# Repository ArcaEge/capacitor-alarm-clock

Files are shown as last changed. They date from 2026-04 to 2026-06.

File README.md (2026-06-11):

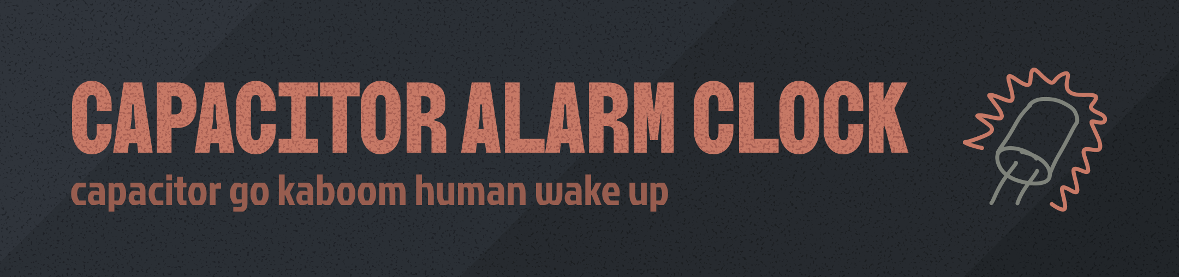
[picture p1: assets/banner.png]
capacitor alarm clock


<div align="center">
    <h1>
        capacitor alarm clock
    </h1>
    <p>
        <strong>
            wake up to the bang of a capacitor going off
        </strong>
    </p>
    <p>
        <a href="#features">Features</a> •
        <a href="#demo">Demo</a> •
        <a href="#pcb">PCB</a> •
        <a href="#cad-files">CAD</a> •
        <a href="#building--flashing-firmware">Firmware</a> •
        <a href="#usage">Usage</a>
    </p>
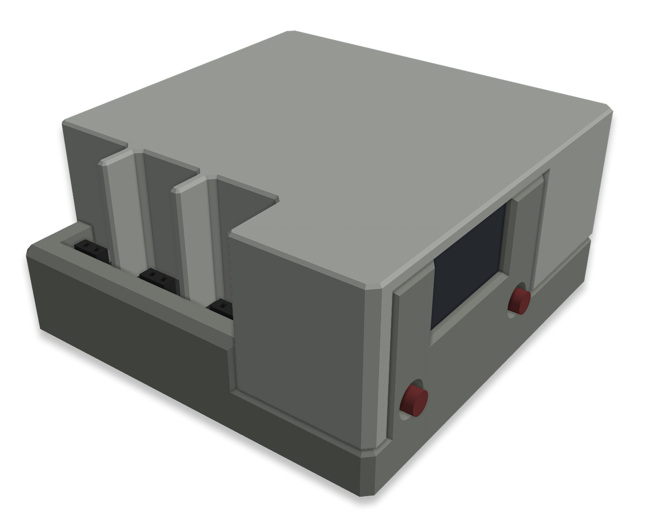
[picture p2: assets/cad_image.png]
CAD image
    
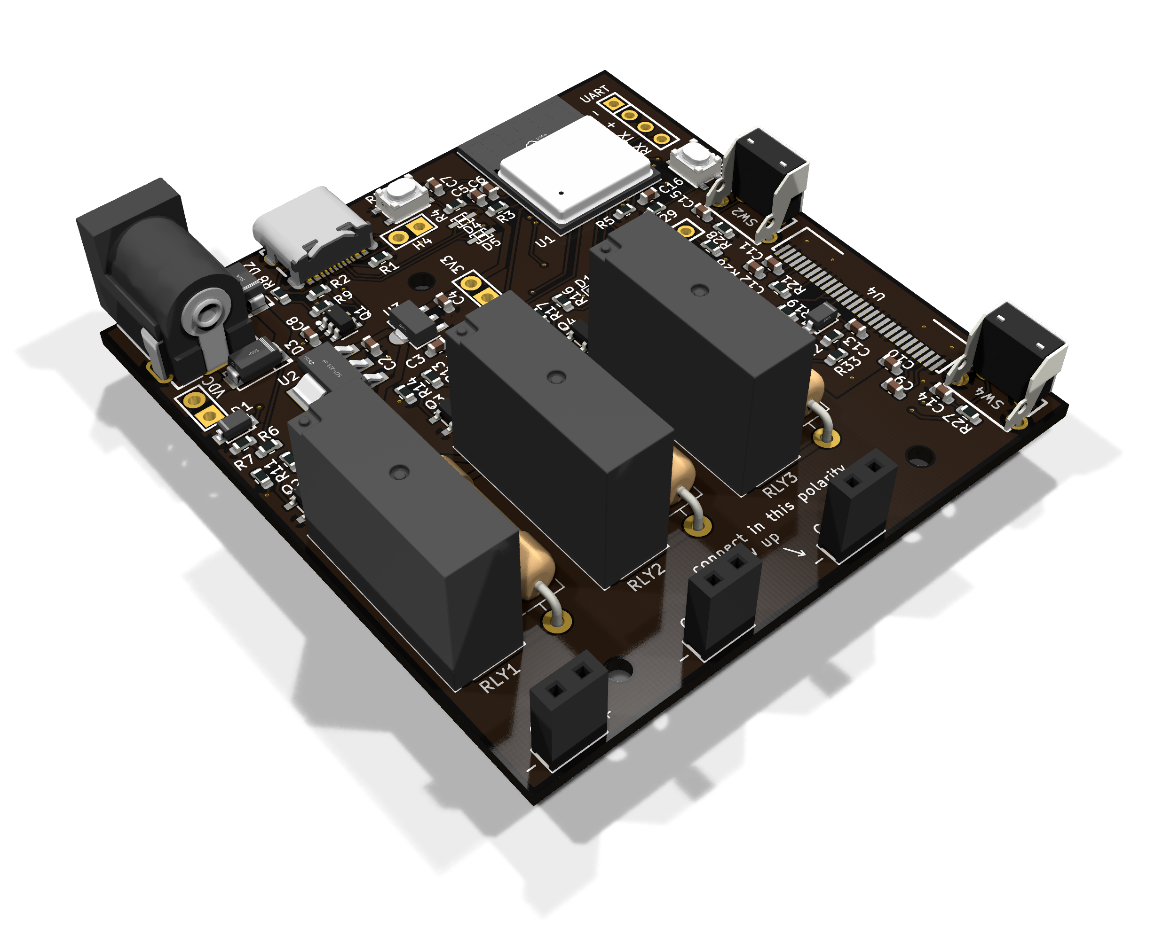
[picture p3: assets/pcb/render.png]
PCB render
    
</div>

## Why?

Why not?

This was originally inspired by ElectroBOOM's [capacitor alarm video](https://www.youtube.com/watch?v=5dYt34JIDGw); this is like a safer (?), more practical and more useable-ish version of that.

> [!WARNING]
> Take care when using this, and only do so if you know what you're doing. Capacitor explosions are quite violent and the fumes aren't nice to breathe. This project is mostly a high-effort joke and not something practical to use

## Features

- ESP32-powered
  - Configure settings via the webserver
  - Fetch time automatically via NTP
- 128x64 SSD1315 display
- 3 separate capacitor slots
- Up to 3A through the capacitors
  - 10 ohm current limiting resistors to avoid brownouts if the capacitor shorts
- Power via USB-C or barrel jack (12-15V)
- Small size (72x74x36mm)

Here's how it looks:

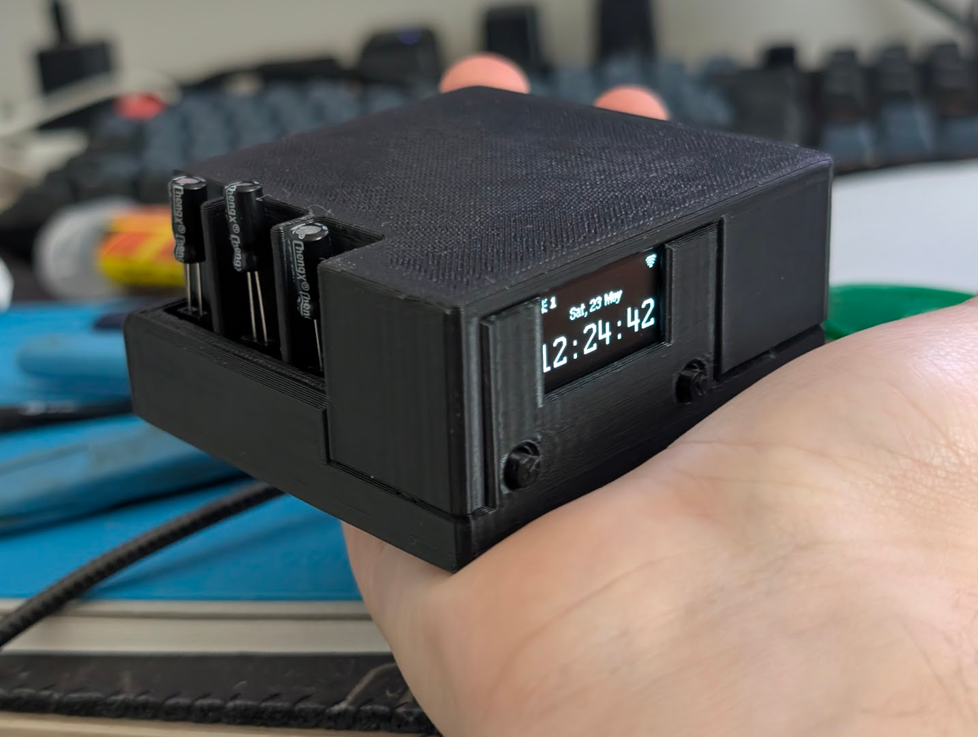
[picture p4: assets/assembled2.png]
assembled capacitor alarm clock resting on hand


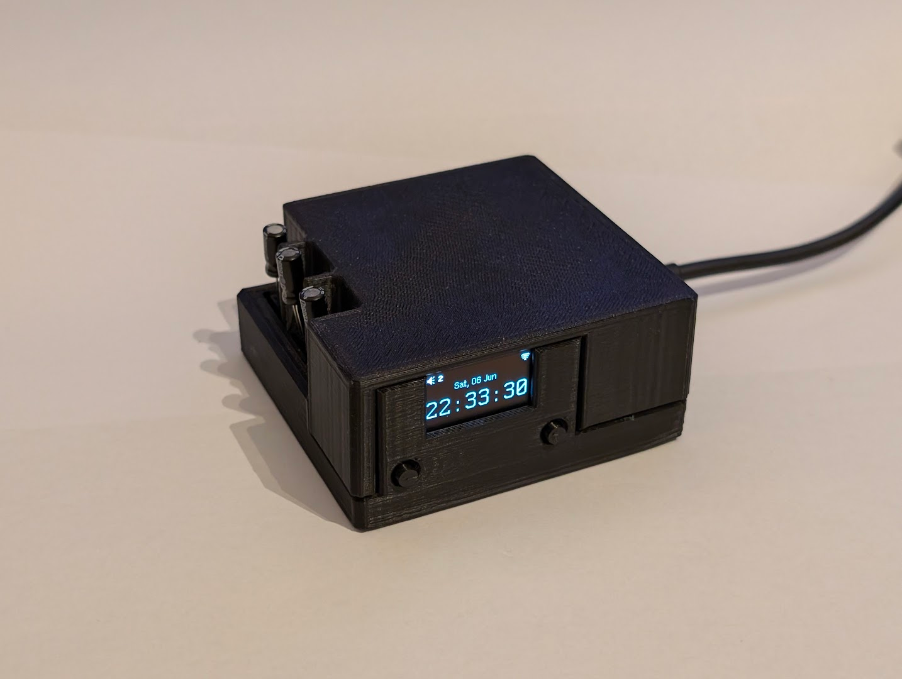
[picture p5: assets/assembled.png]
assembled


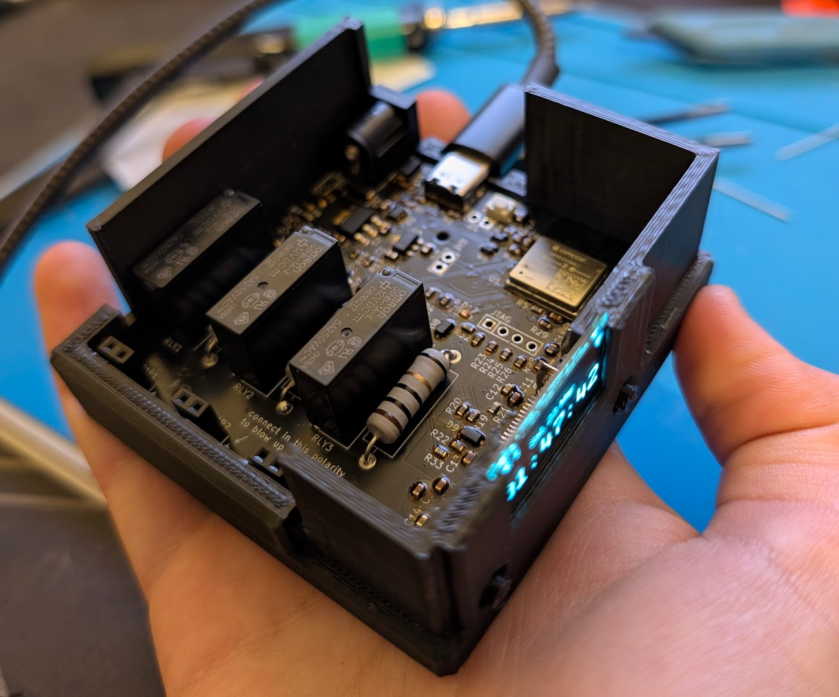
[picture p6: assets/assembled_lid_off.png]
assembled


## Demo

Also on YouTube [here](https://youtu.be/eKc19qRxZ5o)

https://github.com/user-attachments/assets/c24133be-e630-4c25-ad7a-87afec26e37d

## PCB

Images of schematics and more are under the [PCB README](pcb/README.md). A BOM is available under [production](production/). I'd recommend using [JLCPCB](https://jlcpcb.com/) as they seem to have the lowest prices.

<a href="pcb/README.md">
    
</a>

## CAD files

CAD files for the shell and PCB are under [`cad/`](cad/). The README there contains more info, but the Onshape project is available [here](https://cad.onshape.com/documents/62d468c7ff14a2e83cb50980/w/ededd05b0c271bca944a2c41/e/b2699bc116bdf7662263df84).

## Building + flashing firmware

To build and flash the firmware, you'll need to use PlatformIO. Install the VSCode extension and open the firmware folder, then follow the instructions in the [firmware README](firmware/README.md).

## Usage

Once flashed and connected to WiFi, the display will show the current time. You can go into the settings by pressing "select" (done by pressing both buttons at once). From there, you can use the left and right buttons to go up and down and set the alarm time, schedule, next capacitor slot and more. You can also go into the "about" page to see the clock's IP.

Once you have the IP, you can go to the web interface at `http://<IP>/`. Note: some browsers might only try HTTPS (looking at you Firefox), so you'll need to manually enter the `http://` part.

> [!NOTE]
> The voltage regulators might heat up a bit during use, this is normal as there's ~12V of voltage drop across them. It might be a better idea to use a buck converter circuit instead of voltage regulators to step down the voltage. I chose voltage regulators to save on board space, but they do get quite hot. A buck converter circuit would also enable the use of higher input voltages, as the limiting factor right now is thermals.

## Sourcing capacitors

When choosing capacitors, you should avoid capacitors with these pressure release slots at the top, as they will reduce the bang. Choose the biggest capacitor you can get that has no top slot.

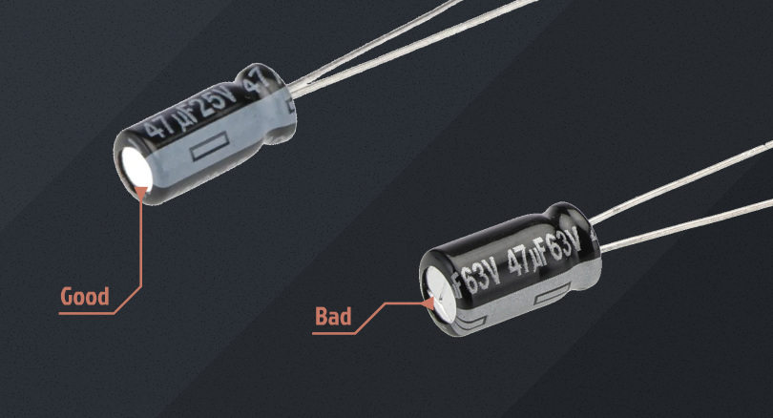
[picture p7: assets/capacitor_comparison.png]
capacitor comparison


Also try to go as low as possible with the voltage rating to increase reliability, ~16V is where you should aim. [These capacitors](https://www.lcsc.com/product-detail/C22320.html) from LCSC are pretty good, at $3 for 200.

## Magazine page

This project was submitted to [Hack Club Fallout](https://fallout.hackclub.com)! Here's the page for the Fallout magazine:

<a href="assets/magazine/magazine.pdf">
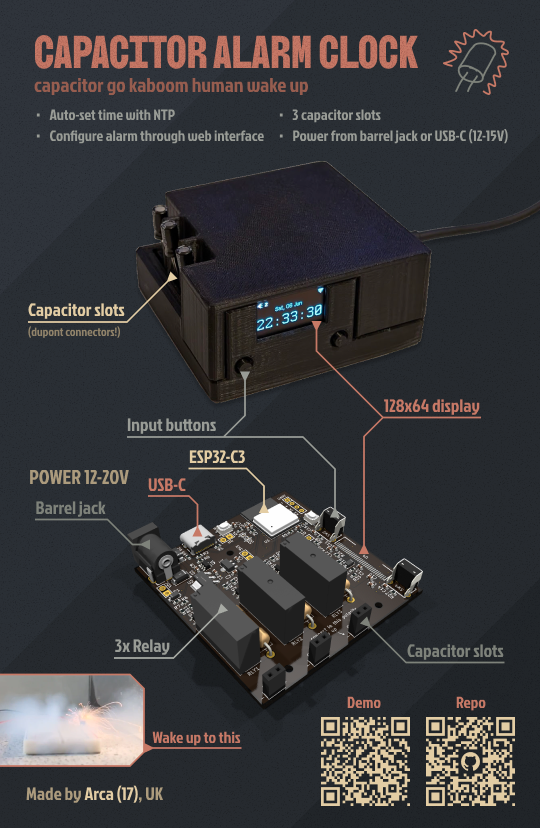
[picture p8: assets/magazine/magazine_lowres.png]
magazine page
    
</a>

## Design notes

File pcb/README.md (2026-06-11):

# PCB files

If you're looking for the production files, they're under [`../production/`](../production/)

PCB render

## PCB

### Front

front

### Back

back

## Schematics

I used hierarchical schematics whilst designing this, this is split into multiple files

### `capacitor-alarm-clock.kicad_sch`

capacitor-alarm-clock.kicad_sch

### `esp32.kicad_sch`

esp32.kicad_sch

### `power.kicad_sch`

power.kicad_sch

### `usb.kicad_sch`

usb.kicad_sch

### `relays.kicad_sch`

relays.kicad_sch

### `display.kicad_sch`

display.kicad_sch

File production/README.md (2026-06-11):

# Production files

## BOM

- [`bom_pcb_components.csv`](bom_pcb_components.csv) - BOM for the PCB components
- [`bom_general.csv`](bom_general.csv) - general BOM with prices

All the electrical components are from LCSC, as it's cheaper.

### LCSC cart

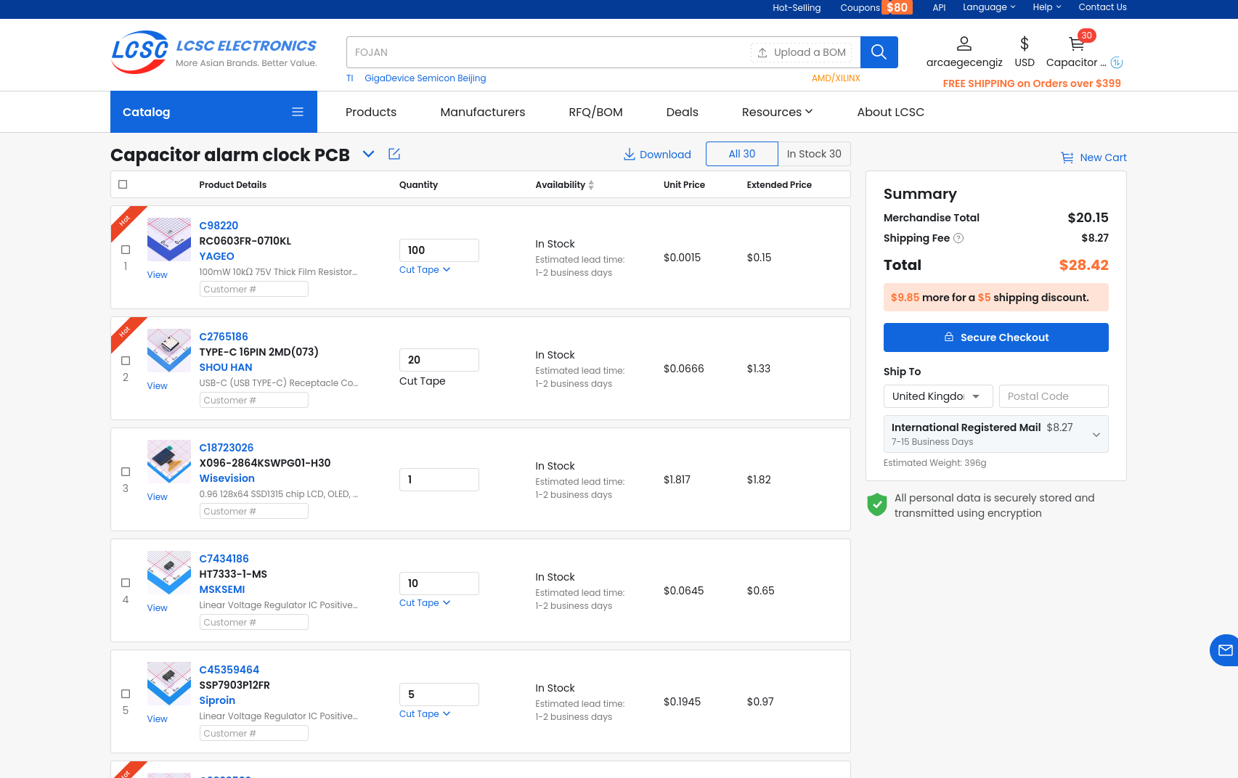
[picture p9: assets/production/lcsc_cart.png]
LCSC cart


## Gerbers & drill files

Under `gerber_drl` and also as a zip at `gerber_drl.zip`

### JLCPCB cart

JLCPCB seems to be the best place to order this, at $2 before shipping:

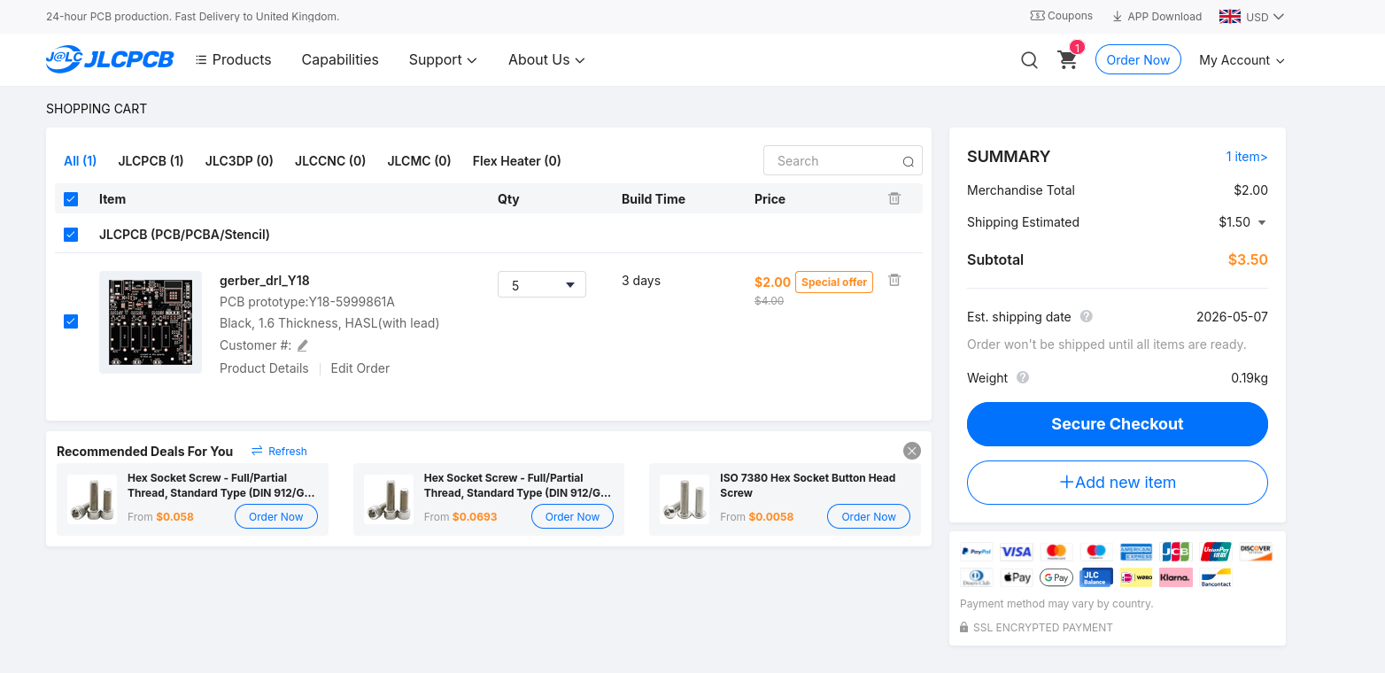
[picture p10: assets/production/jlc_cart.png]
JLCPCB cart


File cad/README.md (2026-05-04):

# CAD files

The Onshape project is [available here](https://cad.onshape.com/documents/62d468c7ff14a2e83cb50980/w/ededd05b0c271bca944a2c41/e/b2699bc116bdf7662263df84)

The top and bottom halves are held together via a friction fit to reduce the need for screws. However, you'll still need M2x5 screws for mounting the PCB to the bottom enclosure.

Takes around 60g of filament to print.

CAD

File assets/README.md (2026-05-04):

# Assets

3D PCB renders were generated with KiCAD CLI, using the `render` command.

Banner and poster designs were designed in Figma, [available here](https://www.figma.com/design/jmvWcAlcJrcGd9PXcn2myq/Capacitor-alarm-clock). The colour palette used is from [here](https://colordesigner.io/color-palette-builder#703030-2F343B-7E827A-E3CDA4-C77966).

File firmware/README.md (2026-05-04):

# firmware

Before compilation, copy `src/config.h.example` to `config.h` and add your WiFi credentials, along with your timezone string. You can then upload to the board.

I didn't have an ESP32 whilst working on the firmware as the parts hadn't arrived yet, so you can also compile this to run on an ESP8266. Choose `nodemcuv2` as the build target to do this. The pinout is in `inputs.hpp`, `alarm.cpp` and `display.hpp`.

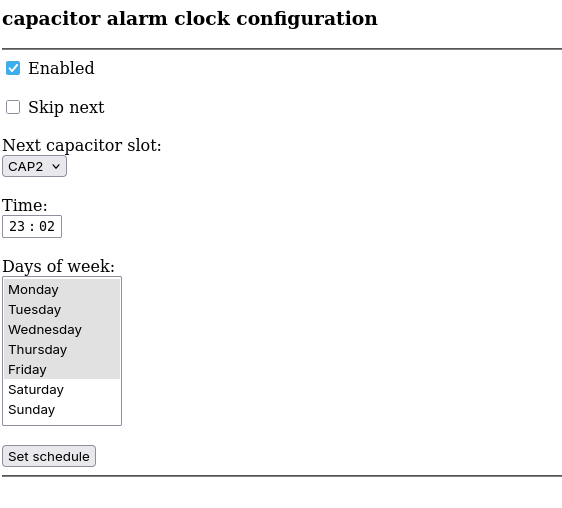
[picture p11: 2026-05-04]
assets/web_config.png

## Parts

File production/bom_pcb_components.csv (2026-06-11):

Reference | Value | Qty | Footprint | Manufacturer Part | Supplier | Supplier Part | Supplier Part URL
C1,C2,C3,C4,C5,C13 | 10u | 6 | Capacitor_SMD:C_0603_1608Metric | CL10A106MA8NRNC | LCSC | C96446 | https://www.lcsc.com/product-detail/C96446.html
C6 | 0.1u | 1 | Capacitor_SMD:C_0603_1608Metric | CC0603KRX7R9BB104 | LCSC | C14663 | https://www.lcsc.com/product-detail/C14663.html
C7,C8,C9,C10,C14,C15,C16 | 1u | 7 | Capacitor_SMD:C_0603_1608Metric | CL10B105KA8NNNC | LCSC | C29936 | https://www.lcsc.com/product-detail/C29936.html
C11 | 4.7u | 1 | Capacitor_SMD:C_0603_1608Metric | CL10A475KO8NNNC | LCSC | C19666 | https://www.lcsc.com/product-detail/C19666.html
C12 | 2.2u | 1 | Capacitor_SMD:C_0603_1608Metric | CL10A225KO8NNNC | LCSC | C23630 | https://www.lcsc.com/product-detail/C23630.html
D1 | 3V3 | 1 | EasyEDA_Lib:SOD-123_L2.7-W1.6-LS3.7-RD | BZT52C3V3 | LCSC | C173413 | https://www.lcsc.com/product-detail/C173413.html
D2,D3 |  | 2 | EasyEDA_Lib:SMA_L4.4-W2.6-LS5.0-RD | B340A-13-F | LCSC | C85098 | https://www.lcsc.com/product-detail/C85098.html
D4,D5 |  | 2 | EasyEDA_Lib:SOD-323_L1.8-W1.3-LS2.5-BI | PESD5V0U1BA-N | LCSC | C406223 | https://www.lcsc.com/product-detail/C406223.html
D6,D7,D8,D9 |  | 4 | EasyEDA_Lib:SOD-123_L2.7-W1.6-LS3.7-RD | 1N5819HW-7-F | LCSC | C82544 | https://www.lcsc.com/product-detail/C82544.html
D10,D11,D12 | LED | 3 | LED_SMD:LED_0603_1608Metric | YLED0603R | LCSC | C19171390 | https://www.lcsc.com/product-detail/C19171390.html
DC1 |  | 1 | EasyEDA_Lib:DC-IN-TH_DC-005-A200 | DC-005-A200 | LCSC | C720557 | https://www.lcsc.com/product-detail/C720557.html
H6,H7,H8 |  | 3 | EasyEDA_Lib:HDR-TH_2P-P2.54-V-F | ZX-PM2.54-1-2PY | LCSC | C7499322 | https://www.lcsc.com/product-detail/C7499322.html
Q1 |  | 1 | EasyEDA_Lib:SOT-23-6_L2.9-W1.6-P0.95-LS2.8-BL-2 | CH221K | LCSC | C5125736 | https://www.lcsc.com/product-detail/C5125736.html
Q2,Q3,Q4 |  | 3 | EasyEDA_Lib:SOT-23-3_L2.9-W1.6-P1.90-LS2.8-BR | BC817-40,215 | LCSC | C52801 | https://www.lcsc.com/product-detail/C52801.html
R1,R2,R19,R20,R22 | 5K1 | 5 | Resistor_SMD:R_0603_1608Metric | FRC0603F5101TS | LCSC | C2907044 | https://www.lcsc.com/product-detail/C2907044.html
R3,R4,R5,R6,R11,R14,R17,R27,R28,R29 | 10K | 10 | Resistor_SMD:R_0603_1608Metric | RC0603FR-0710KL | LCSC | C98220 | https://www.lcsc.com/product-detail/C98220.html
R7 | 62K | 1 | Resistor_SMD:R_0603_1608Metric | RC0603FR-0762KL | LCSC | C137694 | https://www.lcsc.com/product-detail/C137694.html
R8,R10,R13,R16,R30,R31,R32,R33 | 1K | 8 | Resistor_SMD:R_0603_1608Metric | RC0603FR-071KL | LCSC | C22548 | https://www.lcsc.com/product-detail/C22548.html
R9 | 100K | 1 | Resistor_SMD:R_0603_1608Metric | FRC0603F1003TS | LCSC | C2906980 | https://www.lcsc.com/product-detail/C2906980.html
R12,R15,R18 | 10R | 3 | Resistor_THT:R_Axial_DIN0516_L15.5mm_D5.0mm_P20.32mm_Horizontal | MOF3WS-5.1Ω±5% T | LCSC | C121777 | https://www.lcsc.com/product-detail/C121777.html
R21 | 620K | 1 | Resistor_SMD:R_0603_1608Metric | 0603WAF6203T5E | LCSC | C23219 | https://www.lcsc.com/product-detail/C23219.html
R23,R24,R25,R26 | 0R | 4 | Resistor_SMD:R_0603_1608Metric | RC0603JR-070RL | LCSC | C95177 | https://www.lcsc.com/product-detail/C95177.html
RLY1,RLY2,RLY3 |  | 3 | EasyEDA_Lib:RELAY-TH_G5NB-1A-E-DCXX | G5NB-1A-E DC12 | LCSC | C225714 | https://www.lcsc.com/product-detail/C225714.html
SW1,SW3 |  | 2 | EasyEDA_Lib:SW-SMD_4P-L4.2-W3.3-P2.15-LS5.1 | TS-1089S-02526 | LCSC | C455282 | https://www.lcsc.com/product-detail/C455282.html
SW2,SW4 |  | 2 | EasyEDA_Lib:SW-TH_TS665ZJ | TS665ZJ | LCSC | C557599 | https://www.lcsc.com/product-detail/C557599.html
U1 |  | 1 | EasyEDA_Lib:WIFIM-SMD_ESP32-C3-MINI-1 | ESP32-C3-MINI-1-N4 | LCSC | C2838502 | https://www.lcsc.com/product-detail/C2838502.html
U2 |  | 1 | EasyEDA_Lib:SOT-223_L6.3-W3.5-P2.30-LS7.0-BR | SSP7903P12FR | LCSC | C45359464 | https://www.lcsc.com/product-detail/C45359464.html
U3 |  | 1 | EasyEDA_Lib:SOT-223-3_L6.5-W3.4-P2.30-LS7.0-BR-1 | SSP7903P33FR | LCSC | C5199839 | https://www.lcsc.com/product-detail/C5199839.html
U4 |  | 1 | EasyEDA_Lib:OLED-SMD_X096-2864KSWPG01-H30 | X096-2864KSWPG01-H30 | LCSC | C18723026 | https://www.lcsc.com/product-detail/C18723026.html
USB1 |  | 1 | EasyEDA_Lib:USB-C-SMD_TYPE-C-6PIN-2MD-073 | TYPE-C 16PIN 2MD(073) | LCSC | C2765186 | https://www.lcsc.com/product-detail/C2765186.html

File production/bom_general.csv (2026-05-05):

Thing | Qty needed | URL | Cost (without shipping, $)
PCB | 1 | https://jlcpcb.com/ | 2.00
Components | - | https://www.lcsc.com/ | 20.15
Capacitors | 100 | https://www.lcsc.com/product-detail/C22320.html | 1.50
M2x5 screws | 3 | https://jlcmc.com/product/s/E02/EDLA/din-912-gb-t-70.1-standard-socket-head-cap-screws-full---half-thread (part number EDLA-J9-M2-L5) | 0.04

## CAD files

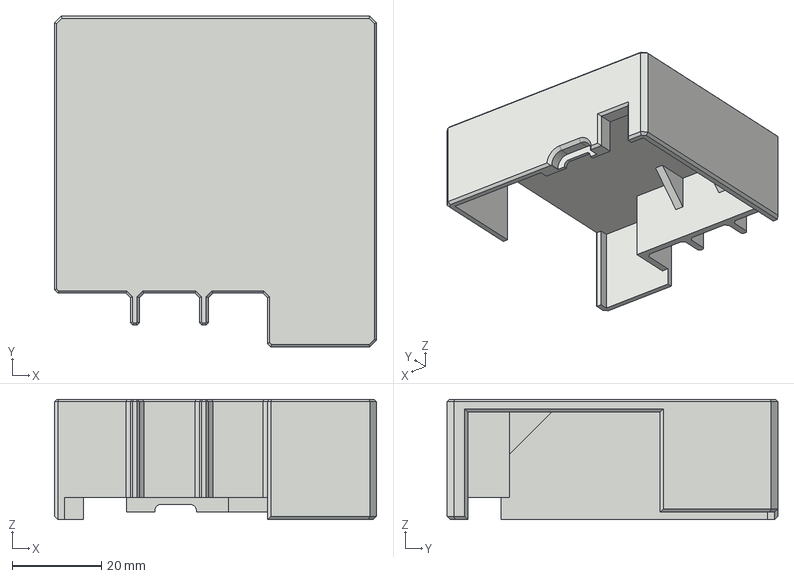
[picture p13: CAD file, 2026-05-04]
cad/step/top_enclosure.step
72.3 x 74.3 x 27.0 mm

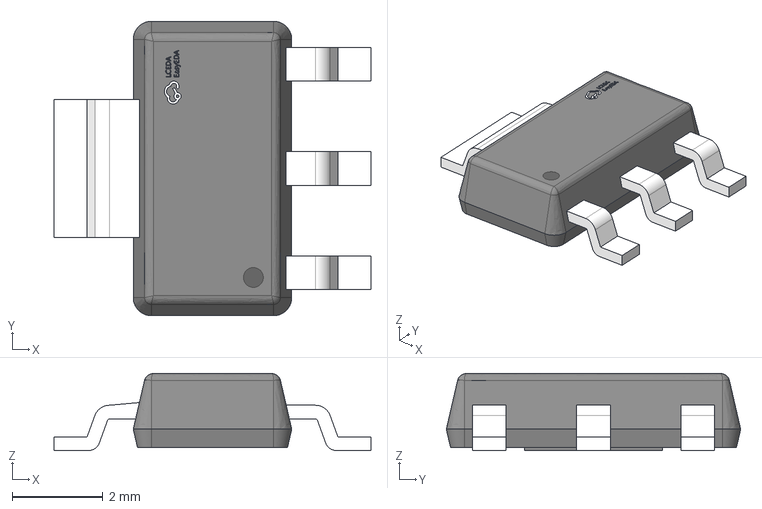
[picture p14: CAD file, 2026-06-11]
pcb/EASYEDA_MODELS/SOT-223-3_L6.5-W3.4-P2.30-LS7.0-BR-1.step
7.00 x 6.50 x 1.70 mm

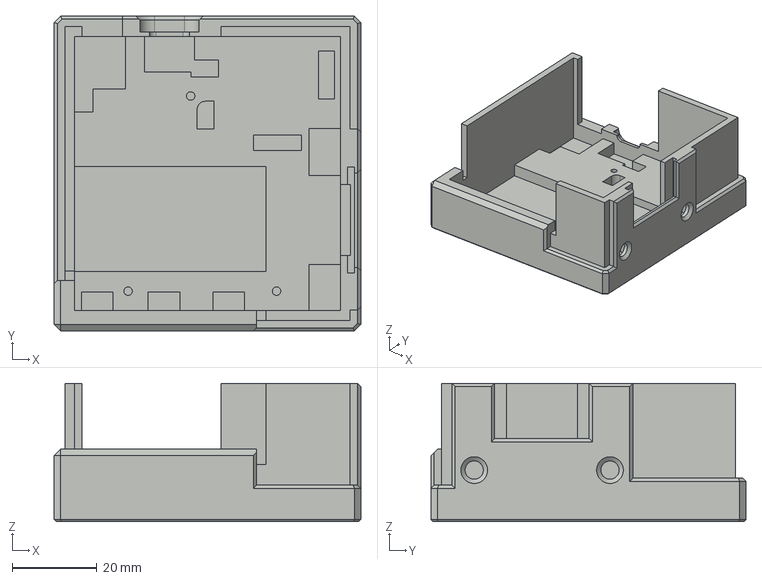
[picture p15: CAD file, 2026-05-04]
cad/step/bottom_enclosure.step
72.3 x 74.3 x 32.6 mm

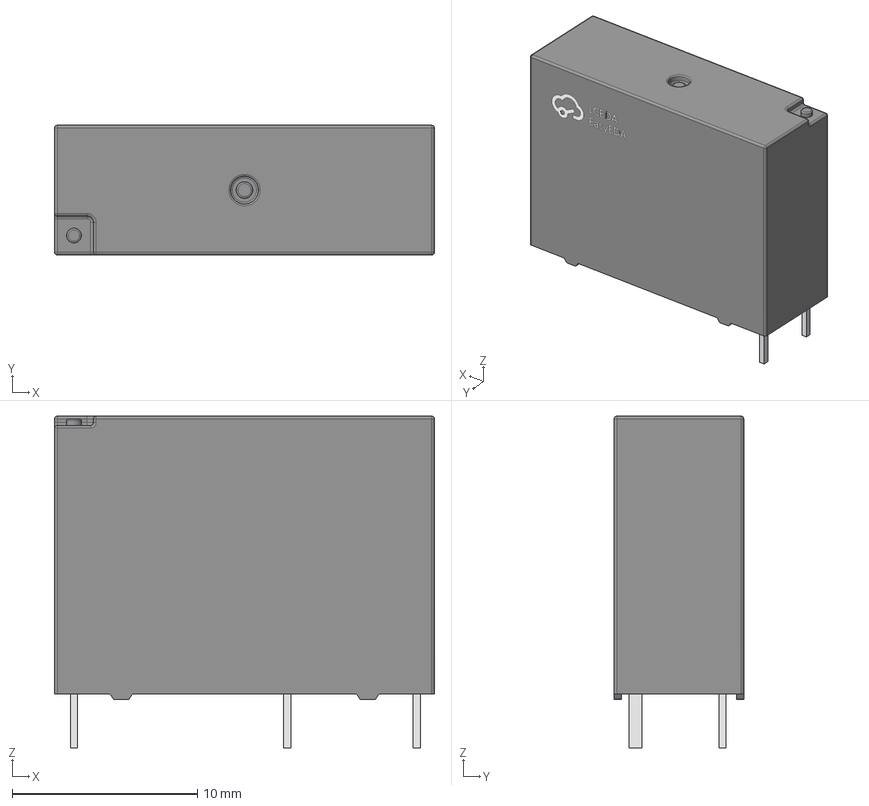
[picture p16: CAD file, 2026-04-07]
pcb/EASYEDA_MODELS/RELAY-TH_L20.5-W7.0-H15.0.step
20.5 x 7.01 x 17.9 mm

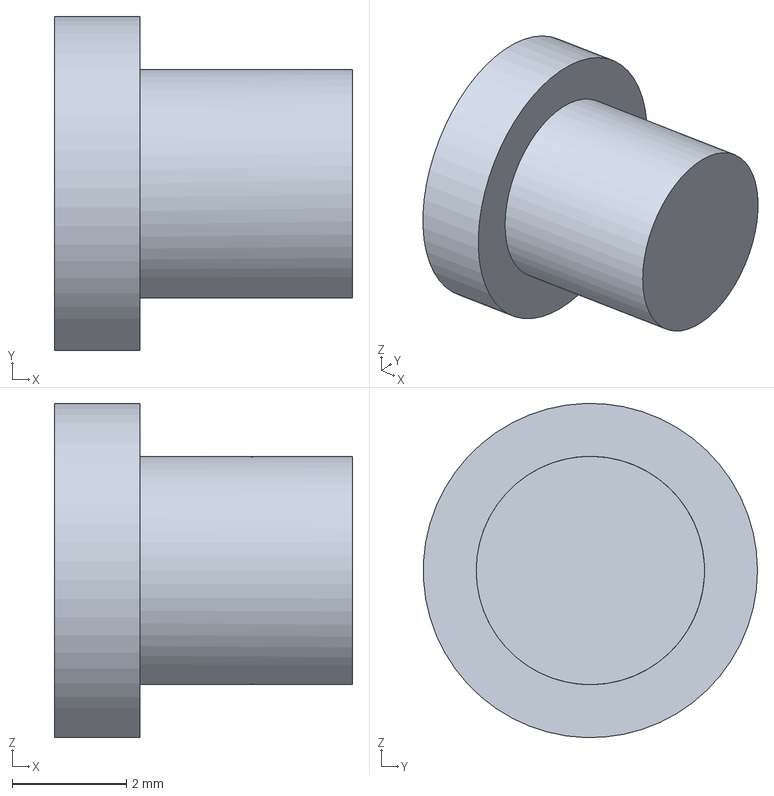
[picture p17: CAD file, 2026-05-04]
cad/step/button.step
5.23 x 5.85 x 5.85 mm

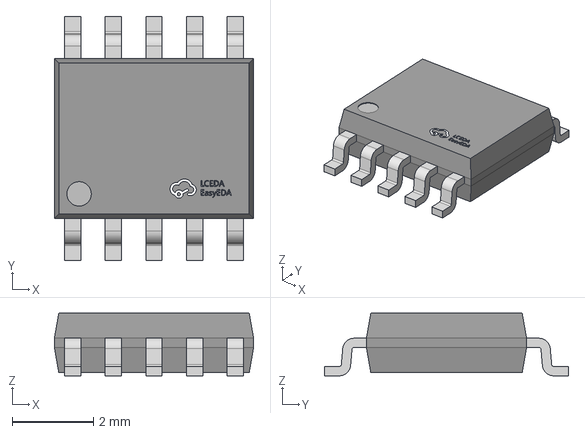
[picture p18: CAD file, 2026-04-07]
pcb/EASYEDA_MODELS/ESSOP-10_L4.9-W3.9-P1.0-LS6.0-TL-EP.step
4.90 x 6.00 x 1.54 mm

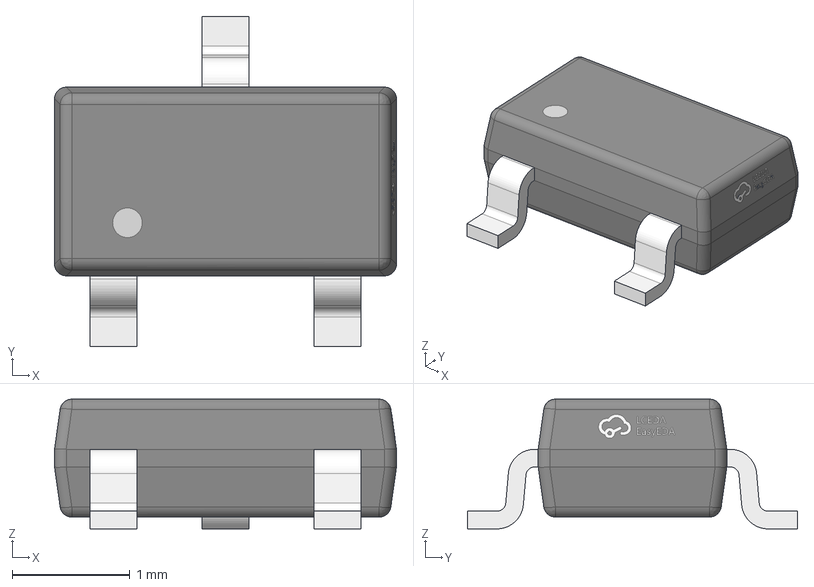
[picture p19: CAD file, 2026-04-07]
pcb/EASYEDA_MODELS/SOT-23-3L_L2.9-W1.6-H1.1-LS2.8-P0.95.step
2.90 x 2.80 x 1.10 mm

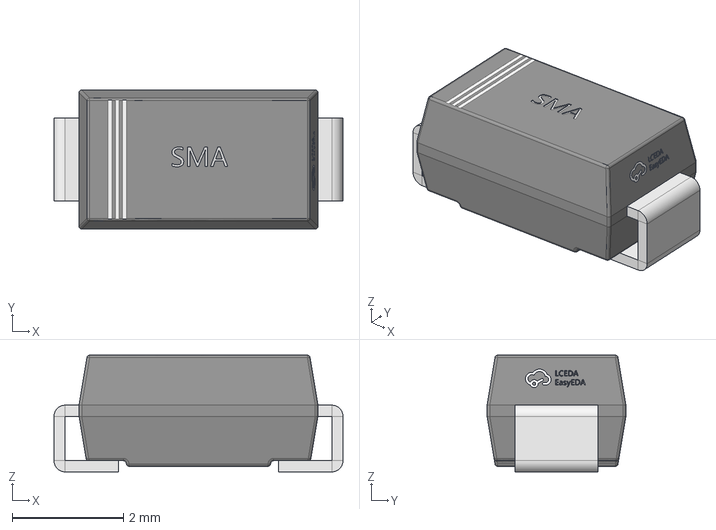
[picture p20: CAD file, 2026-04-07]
pcb/EASYEDA_MODELS/SMA_L4.4-W2.6-LS5.0-RD.step
5.20 x 2.50 x 2.10 mm

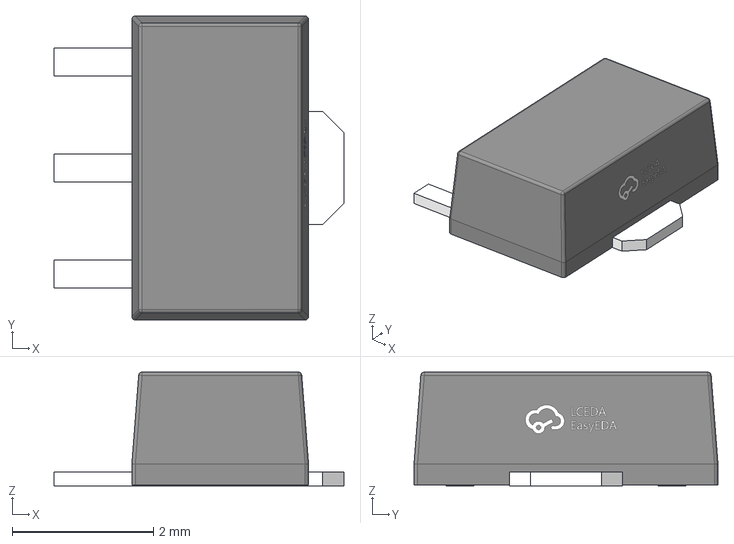
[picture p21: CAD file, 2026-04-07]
pcb/EASYEDA_MODELS/SOT-89-3_L4.3-W2.5-H1.6-LS4.1-P1.50.step
4.10 x 4.30 x 1.61 mm

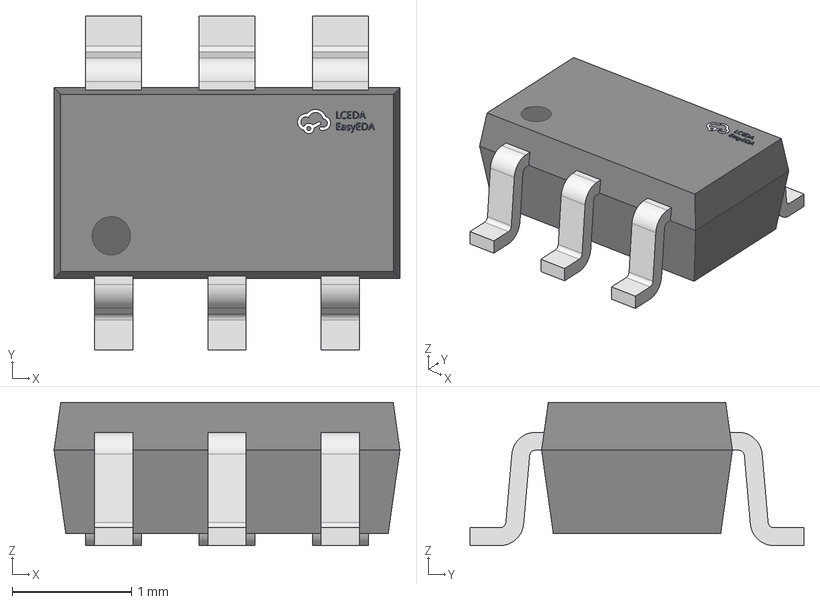
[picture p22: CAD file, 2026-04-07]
pcb/EASYEDA_MODELS/SOT-23-6_L2.9-W1.6-P0.95-LS2.8-BL-2.step
2.90 x 2.80 x 1.20 mm

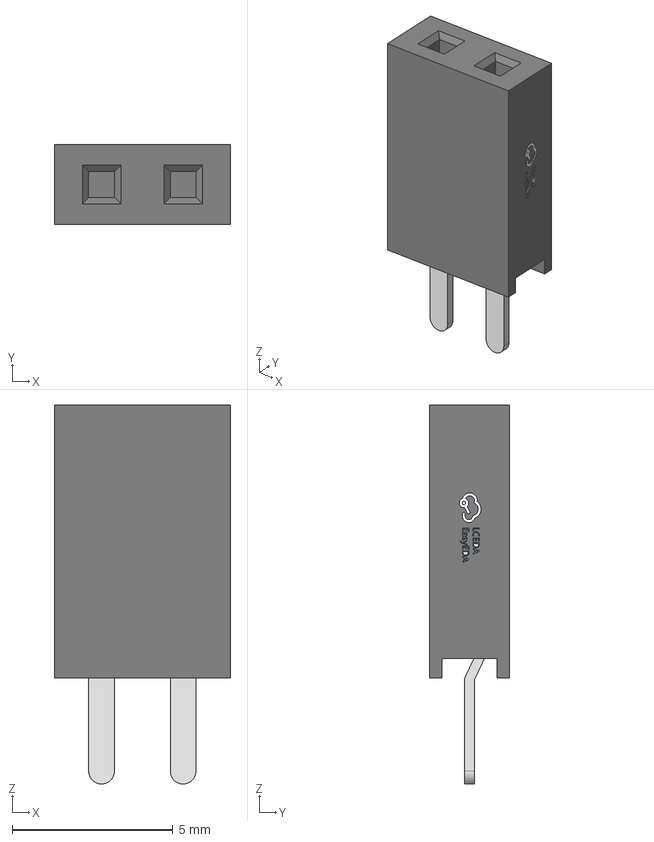
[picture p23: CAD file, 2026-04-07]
pcb/EASYEDA_MODELS/HDR-TH_2P-P2.54-F-LI-1X2P.step
5.49 x 2.50 x 11.8 mm

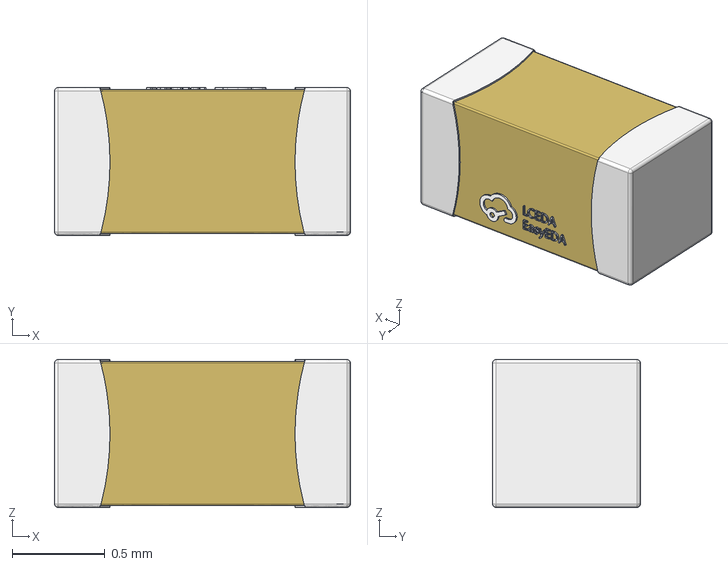
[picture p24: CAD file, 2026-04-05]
pcb/EASYEDA_MODELS/C0603_L1.6-W0.8-H0.8.step
1.60 x 0.8 x 0.8 mm

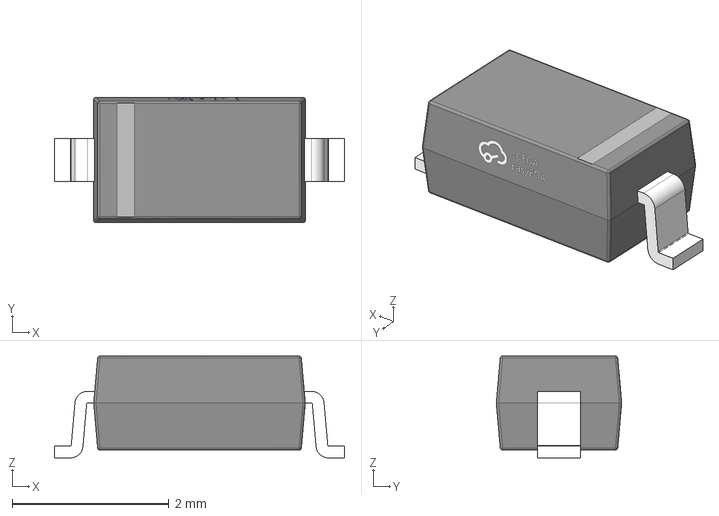
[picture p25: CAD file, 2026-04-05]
pcb/EASYEDA_MODELS/SOD-123_L2.7-W1.6-H1.4-LS3.7.step
3.70 x 1.60 x 1.30 mm

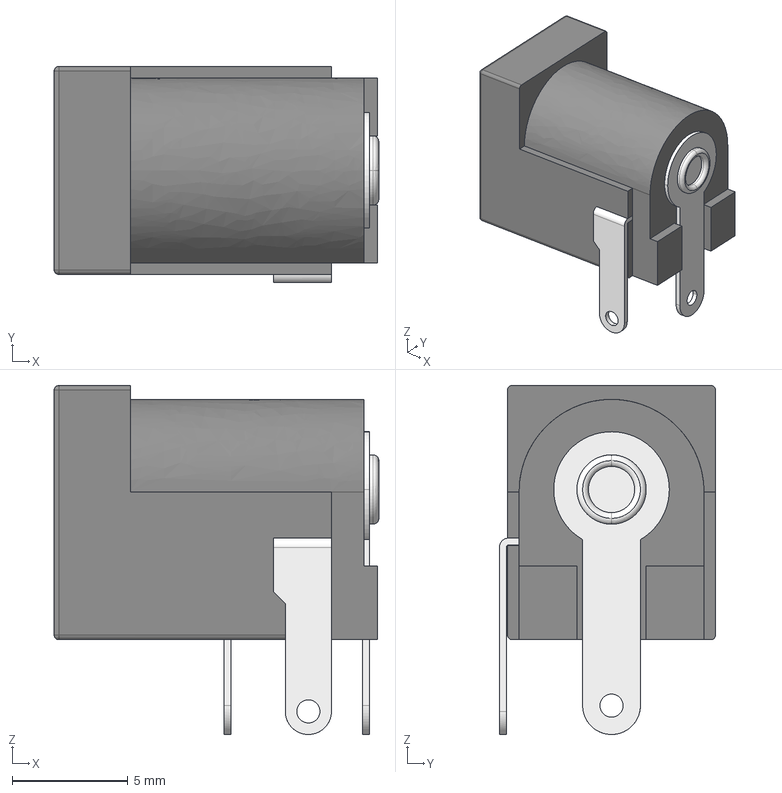
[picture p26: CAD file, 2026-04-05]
pcb/EASYEDA_MODELS/DC-IN-TH_DC-005-A200.step
14.1 x 9.35 x 15.1 mm

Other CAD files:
pcb/EASYEDA_MODELS/SOT-223-4P_L6.5-W3.5-H1.6-LS7.0-P2.30.step
pcb/EASYEDA_MODELS/SW-SMD_4P-L4.2-W3.3-H2.5-P2.15-LS5.1.step
pcb/EASYEDA_MODELS/HDR2.54-M-LI-1X2P.step
pcb/EASYEDA_MODELS/HDR-TH_4P-P2.54-M-LI-1X4P.step
cad/stl/bottom_enclosure.stl
cad/stl/button.stl
cad/stl/top_enclosure.stl
pcb/EASYEDA_MODELS/OSC-SMD_4P-L2.5-W2.0-H0.6.step
pcb/EASYEDA_MODELS/PWRM-TH_WRAXXXXSD-3WR2.step
pcb/EASYEDA_MODELS/USB-C-SMD_TYPE-C-6PIN-2MD-073.step
pcb/EASYEDA_MODELS/WIFIM-SMD_ESP32-C3-MINI-1.step

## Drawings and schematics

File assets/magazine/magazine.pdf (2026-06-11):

## capacitor go kaboom human wake up

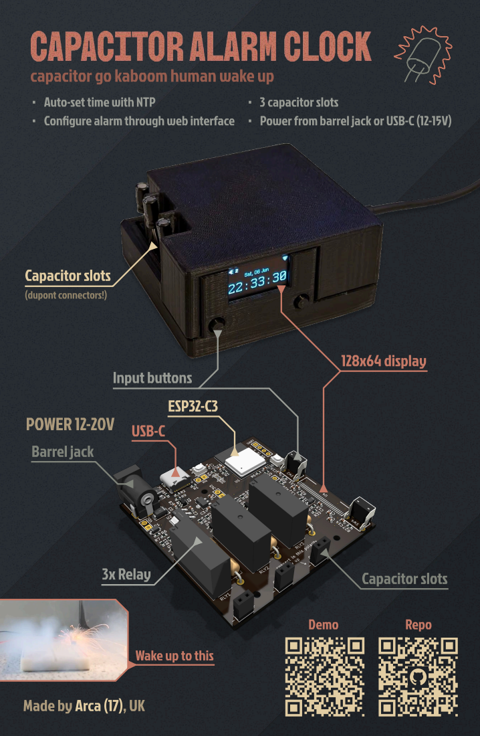
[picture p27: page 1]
Capacitor slots; (dupont connectors!); Input buttons; ESP32-C3; Power 12-20V USB-C; Barrel jack; 128x64 display; 3x Relay; Demo; Repo

Auto-set time with NTP
Configure alarm through web interface

3 capacitor slots
Power from barrel jack or USB-C (12-15V)

Wake up to this

Made by Arca (17), UK

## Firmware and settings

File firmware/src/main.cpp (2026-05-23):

#include "display.hpp"
#include "includes.hpp"
#include "config.h"
#include "server.hpp"
#include "state.hpp"
#include "alarm.hpp"
#include "inputs.hpp"

const char* ntpServer1 = "pool.ntp.org";
const char* ntpServer2 = "time.nist.gov";

const char* time_zone = TZ;

void setup() {
    Serial.begin(115200);

    inputs_init();
    alarm_init();
    display_init(state);

    // Load state
    state.prefs.begin("cap-clock");

    Serial.println("Loading schedule");
    if (state.prefs.getBytes("persistent", &state.persistent, sizeof(state.persistent))) {
        Serial.println("Schedule loaded");
    } else {
        Serial.println("No schedule exists, loaded empty schedule");
    }

    sntp_servermode_dhcp(1);
    configTzTime(time_zone, ntpServer1, ntpServer2);

    WiFi.mode(WIFI_STA);
    WiFi.begin(WIFI_SSID, WIFI_PASSWORD);
}

void loop() {
    state.wifi.connected = WiFi.status() == WL_CONNECTED;

    inputs_loop(state);

    if (state.wifi.connected) {
        state.wifi.ip = WiFi.localIP();

        if (!state.wifi.previouslyConnected) {
            Serial.println("");
            Serial.print("Connected to ");
            Serial.println(WIFI_SSID);
            Serial.print("IP address: ");
            Serial.println(WiFi.localIP());

            if (MDNS.begin("capacitor-alarm-clock")) {
                Serial.println("MDNS responder started");
            }

            server_init(state);
        }

        state.wifi.previouslyConnected = true;

        server_handle();
    }

    if (state.wifi.previouslyConnected)
        state.time.available = getLocalTime(&state.time.info);

    alarm_loop(state);
    display_loop(state);

    delay(2);
}

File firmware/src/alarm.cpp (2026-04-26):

#include "alarm.hpp"

#ifndef BUILD_TEST_ESP8266
// Building for PCB
#define RELAY_1 3
#define RELAY_2 1
#define RELAY_3 10
#else
// Building for test ESP8266
#define RELAY_1 14
#define RELAY_2 12
#define RELAY_3 13
#endif

void alarm_init() {
    pinMode(RELAY_1, OUTPUT);
    pinMode(RELAY_2, OUTPUT);
    pinMode(RELAY_3, OUTPUT);
}

void alarm_loop(State& state) {
    unsigned long now = millis();

    if (state.alarm.stopTriggerAt != 0) {
        // Currently going off
        if (now > state.alarm.stopTriggerAt) {
            uint8_t pin = _alarm_get_pin(state.alarm.currentSlot);

            digitalWrite(pin, LOW);

            state.alarm.stopTriggerAt = 0;
            state.alarm.currentSlot = 0;
        }
    } else if (state.persistent.schedule.enabled) {
        bool timeMatches = state.persistent.schedule.time.hours == state.time.info.tm_hour && state.persistent.schedule.time.minutes == state.time.info.tm_min && state.time.info.tm_sec == 0;
        bool dayOfWeekMatches = state.persistent.schedule.weekSchedule[(state.time.info.tm_wday + 6) % 7];

        if (state.time.available && timeMatches && dayOfWeekMatches) {
            // Is time to go off
            if (state.alarm.skipNext) {
                // Use skip
                state.alarm.skipNext = false;
                state.alarm.lastSkipAt = now;
                Serial.println("skipped");
            } else if (now - state.alarm.lastSkipAt > 5000) {
                // >5s since skip and skipNext is false
                // go boom
                Serial.println("going kaboom");

                state.alarm.stopTriggerAt = now + ALARM_PIN_ON_TIME;

                state.alarm.currentSlot = state.persistent.nextSlot;
                uint8_t pin = _alarm_get_pin(state.alarm.currentSlot);

                digitalWrite(pin, HIGH);

                // (((state.persistent.nextSlot - 1) + 1) % 3) + 1
                state.persistent.nextSlot = (state.persistent.nextSlot % 3) + 1;
                state.prefs.putBytes("persistent", &state.persistent, sizeof(state.persistent));
            }
        }
    }
}

uint8_t _alarm_get_pin(uint8_t slot) {
    switch (slot) {
        case 1:
            return RELAY_1;
        case 2:
            return RELAY_2;
        case 3:
            return RELAY_3;
        default:
            return 0;
    }
}

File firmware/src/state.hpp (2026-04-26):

#pragma once
#include "includes.hpp"
#include <MUIU8g2.hpp>

struct State {
    struct {
        bool connected = false;
        bool previouslyConnected = false;
        IPAddress ip;
    } wifi;

    struct {
        bool available = false;
        tm info;
    } time;

    Preferences prefs;
    MUIU8G2 mui;

    struct {
        struct {
            bool enabled = true;
            struct {
                uint8_t hours = 0;
                uint8_t minutes = 0;
            } time;
            bool weekSchedule[7] = {false};
        } schedule;

        uint8_t nextSlot = 1;
    } persistent;

    struct {
        bool skipNext = false;
        
        unsigned long stopTriggerAt = 0;
        unsigned long lastSkipAt = 0;

        uint8_t currentSlot = 0;
    } alarm;

    struct {
        struct {
            bool prev = false;
            bool next = false;
            bool select = false;
        } events;
        struct {
            bool bothPressed = false;

            // States of left + right buttons from the last loop
            bool leftLast = false;
            bool rightLast = false;
        } raw;
    } input;
};

extern State state;

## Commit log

2026-04-05 Finished the power, USB and ESP32 parts of the schematic
    [C0603_L1.6-W0.8-H0.8.step, DC-IN-TH_DC-005-A200.step, HDR-TH_4P-P2.54-M-LI-1X4P.step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]
2026-04-07 Finished schematics, started component placement
    [ESSOP-10_L4.9-W3.9-P1.0-LS6.0-TL-EP.step, HDR-TH_2P-P2.54-F-LI-1X2P.step, RELAY-TH_L20.5-W7.0-H15.0.step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]
2026-04-08 Pretty much finished the PCB, only got the silkscreen decorations left
    [capacitor-alarm-clock.kicad_pcb, esp32.kicad_sch, relays.kicad_sch]
2026-04-11 Update PCB silkscreen
    [capacitor-alarm-clock.kicad_pcb]
2026-04-12 Flipped the display footprint so it faces the correct way
    [capacitor-alarm-clock.kicad_pcb]
2026-04-12 Change footprint
    [capacitor-alarm-clock.kicad_pcb]
2026-04-12 Move PCB to its own folder
    [C0603_L1.6-W0.8-H0.8.step, DC-IN-TH_DC-005-A200.step, ESSOP-10_L4.9-W3.9-P1.0-LS6.0-TL-EP.step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]
2026-04-14 Connected reset pin to gpio2
    [capacitor-alarm-clock.kicad_pcb, capacitor-alarm-clock.kicad_sch, display.kicad_sch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]
2026-04-24 Button input system done
2026-04-25 copy u8g2 locally to fix library import bug
    [main.cpp, state.hpp]
2026-04-26 Add next slot and one-day disable
    [capacitor-alarm-clock.kicad_pcb]
2026-04-26 Modify pin on time to 25s
2026-05-03 Upgrade kicad version to 10, add krita capacitor image
    [capacitor-alarm-clock.kicad_pcb, capacitor-alarm-clock.kicad_sch, display.kicad_sch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]
2026-05-04 Update firmware to add about page, start improving README
    [capacitor-alarm-clock.kicad_pcb]
2026-05-04 Add CAD files, magazine pages etc. README is pretty much done
    [bottom_enclosure.step, bottom_enclosure.stl, button.step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]
2026-05-04 Add CAD readme and production files
    [capacitor-alarm-clock-B_Cu.gbl, capacitor-alarm-clock-B_Mask.gbs, capacitor-alarm-clock-B_Paste.gbp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]
2026-05-04 Add JLC carts and BOM
    [bom_general.csv, bom_lcsc.xls, bom_pcb_components.csv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]
2026-05-04 kicad_pro got modified
2026-05-05 Update BOM to switch to jlcmc
    [bom_general.csv]
2026-05-05 Fix URL formatting for M2x5 screws entry
    [bom_general.csv]
2026-05-05 Fix cost for M2x5 screws in bom_general.csv
    [bom_general.csv]
2026-05-11 Update 10u capacitor to 25v rated one
    [bom_lcsc.xls, bom_pcb_components.csv, capacitor-alarm-clock.kicad_sch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]
2026-05-23 Switch buttons
2026-05-23 Fix persistence on esp32
    [main.cpp]
2026-05-23 Change input voltage range
    [bom_pcb_components.csv, capacitor-alarm-clock.kicad_pcb, relays.kicad_sch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]
2026-05-23 Update BOM
    [bom_pcb_components.csv]
2026-06-07 Update capacitor time and add assembled images to README
2026-06-11 Improve voltage regulator circuit so it doesn't keep browning out
    [SOT-223-3_L6.5-W3.4-P2.30-LS7.0-BR-1.step, bom_pcb_components.csv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]
